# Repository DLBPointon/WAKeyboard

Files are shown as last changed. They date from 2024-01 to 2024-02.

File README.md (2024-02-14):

# WAK!

Whilst waiting for a replacement for a beautiful split keyboard, the Sofle v2, i jumped into the rabbit hole of Mechanical Keyboards. It didn't help that my daughter now wants her own, so here I am learning in public.

## Build Diary
[Find my build diary here](diary/diary.md)

# Summary
Clearly, there are some glaring faults here.
- The inch thick cavity is not good, if makes a bit of an echo chamber which makes quite the twang when a central button is pressed.
    - Next versions should seat the MCU on top ( like the lumberjack which I think is cool af )or have more fill inside the case. Maybe foam?

- Although the dedicated MCU socket is a good idea, to me anyway, it add ALOT of headroom. Perhaps, if the extra gpio pins pointed downwards so that the socket can pop out of the top and the pins point below... that would be a nice to have and potentially not hard to design...

- Better modelling of the case.

- MAGNETS! These would be much better to secure the top and bottom to the case.

- Wiring, cutting out segments didnt work... heat shrinking tiny bits of shrink. Next time, because there will be a next time. I'll be using magnetic wire.

## The Board
This will be a handwired, wired (for now) build using an RP2040 board (specifically this one [Waveshare RP2040 Plus](https://thepihut.com/products/rp2040-plus?variant=42405935612099), however if that doesn't work out then I have a Pi Pico WH in waiting--which I need to figure out how to hook up to a LiPo) programmed with KMK. For me this makes sense as i'm primarily a Python developer and KMK is built for the RP2040 ecosystem.

## Inspiration
### My Daughter (actual daughter, not a keyboard)
Wanted a "One piece" keyboard, apparently my split board was toooo space ship like... pfft.

### Lumberjack keyboard
I found this very early on in my search across the web, the one piece "split" with the controller in the middle looks pretty cool.

### Sofle v2
Of course, it's cool. I've tried to keep a similar-ish column stagger (more aggresive pinky, and no ring finger stagger). However, i've moved the clusters into the centre of the board ( something I may live to regret, but hey ho ).

## Design

I've designed this board using [Keyboard Layout Editor](http://www.keyboard-layout-editor.com/), writing it all in their raw data json field _before_ realising that there was GUI the whole time. This produces the contents of this file: [layout.json](data/layout.json).
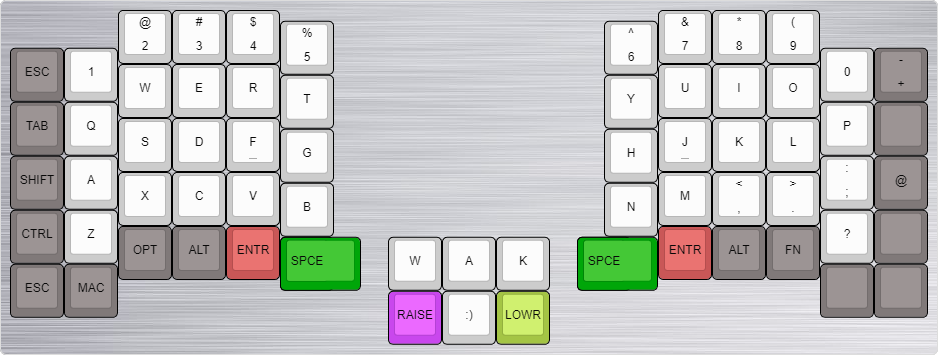
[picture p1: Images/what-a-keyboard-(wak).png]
WAK


Copy Pasting this into [KBFirmware](https://kbfirmware.com/), which I know is EOL but it's great for getting a quick and easy wiring diagram.
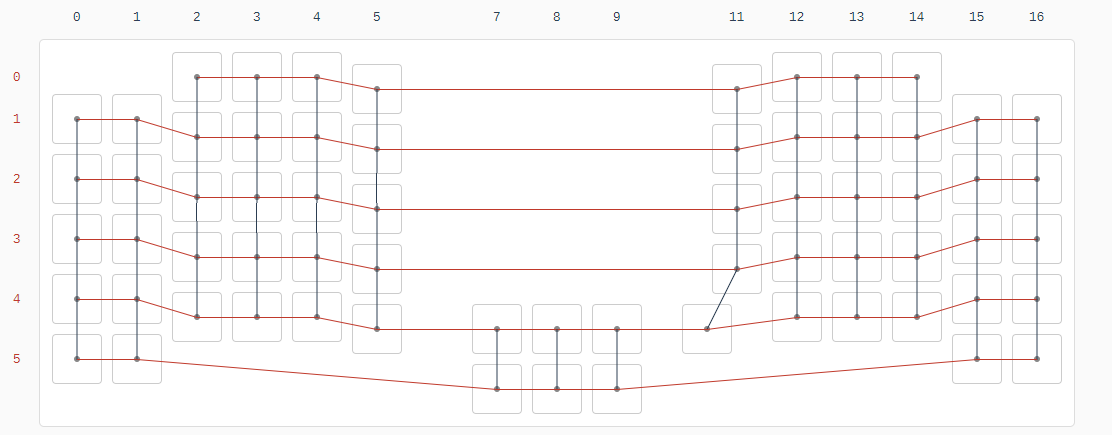
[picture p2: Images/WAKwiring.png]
Wiring


Pasting it into [swillkb's builder app](http://builder.swillkb.com/) will generate some CAD output too. Saved in the cad folder. This looks something like this:
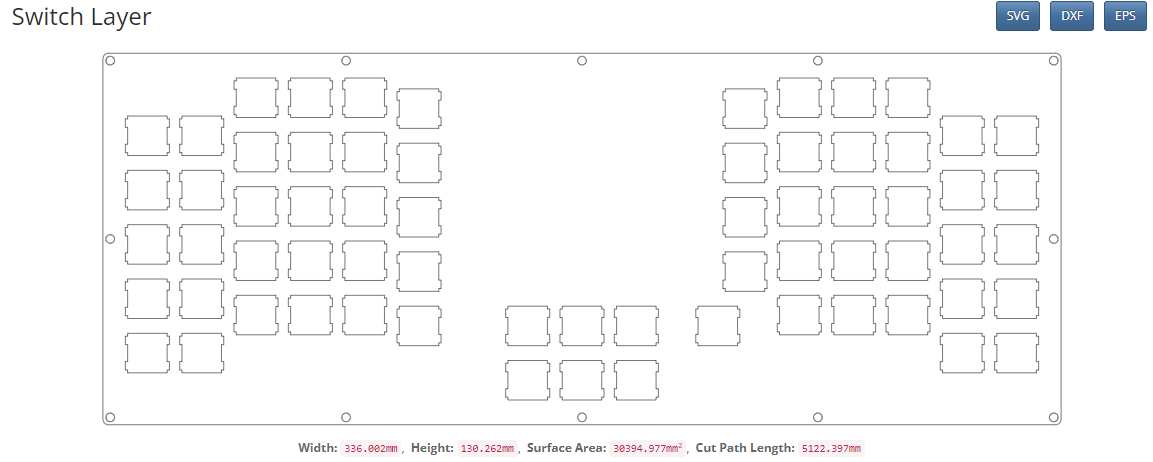
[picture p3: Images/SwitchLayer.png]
Switch Layer


I went to [laserboost](https://www.laserboost.com/en/create) to get the switch and bottom plate cut in Aluminium (This is only a prototype, and I feel like I should have found a 3d printer service too... lessons for the future)

I then thought, hmm... what would make this look very professional? People on the Reddit and the YouTube seem to like KiCad, so I gave it a go and came up with this:
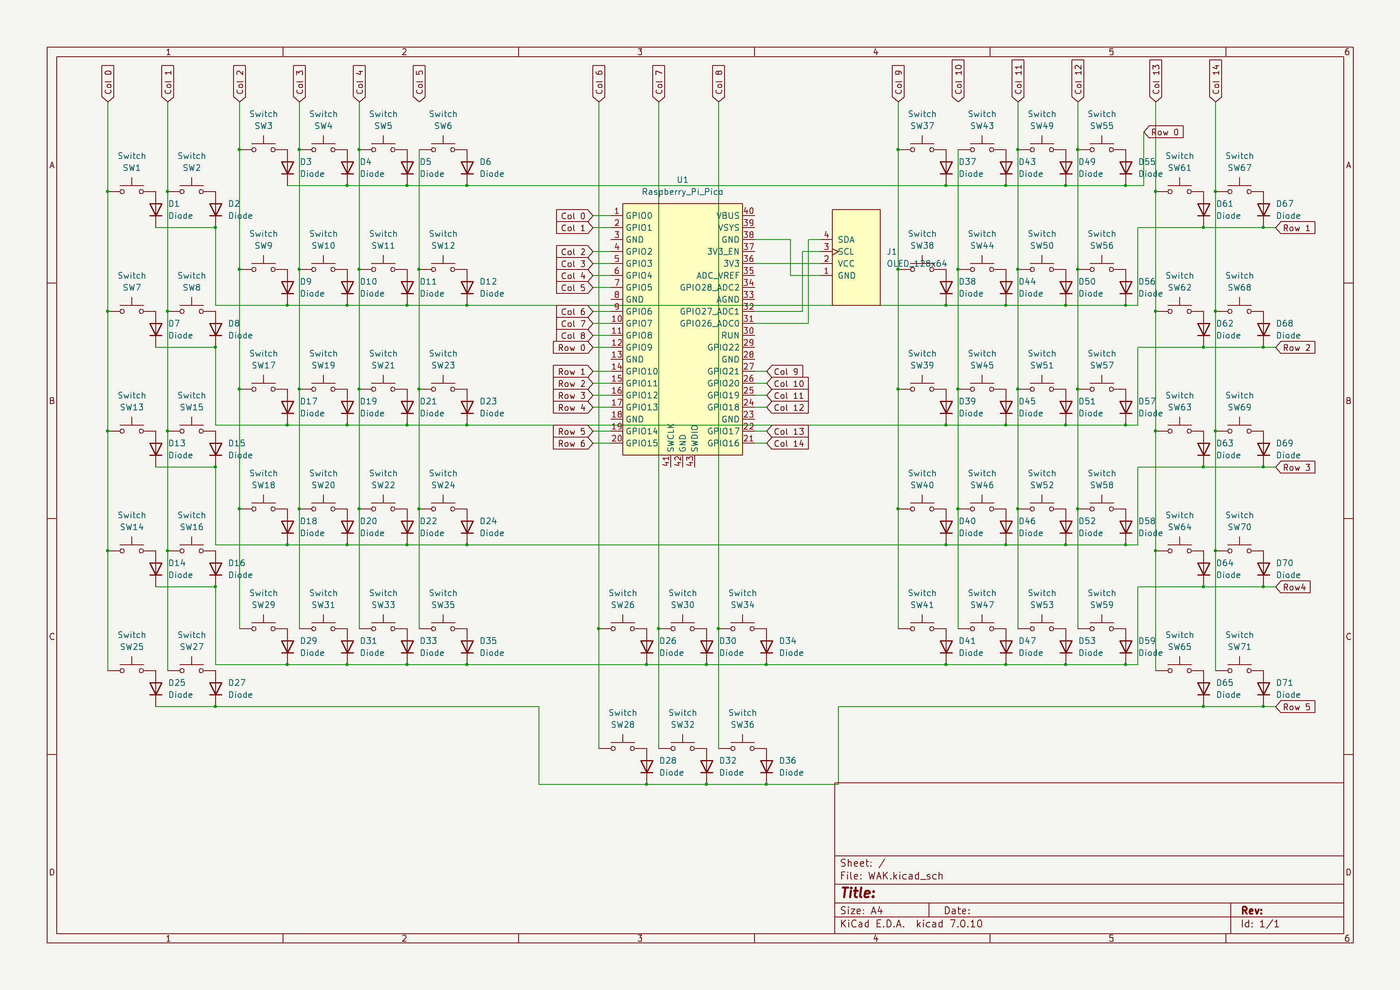
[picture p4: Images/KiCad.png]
KiCad Drawing


I also used this and the ScottoKeebs KiCad repo to generate a PCB, which I will not be getting printed as it is not completed (Some of the lines couldn't route to their pin so I temporarily gave up) and looks trash (from my currently uneducated gaze). It's more here to show it's easy to do after a 3rd viewing of Joe Scotto's tutorial. Look's cool though right?
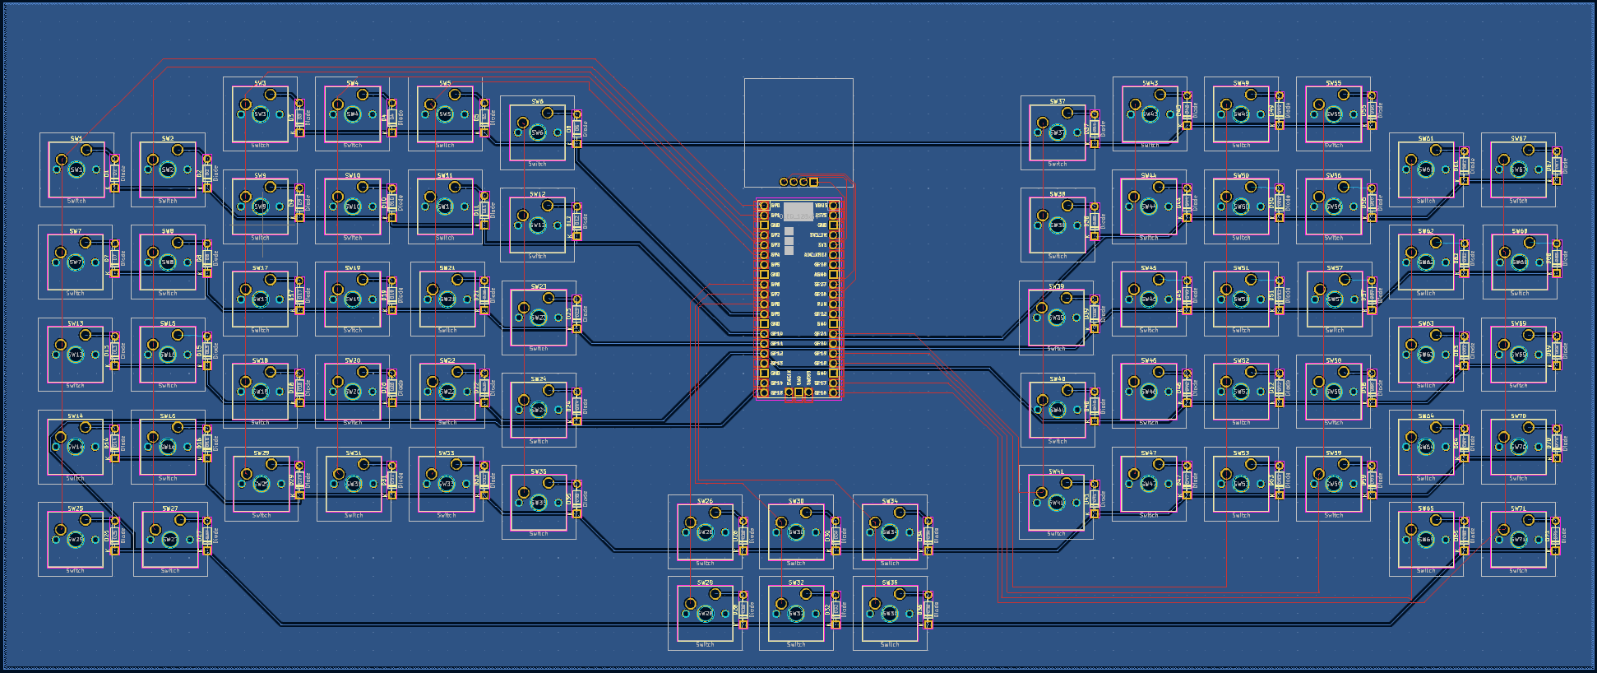
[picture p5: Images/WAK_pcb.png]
WAK_PCB


## Bill Of Materials

My new years resolution is no Amazon so my BoM so far is:

| Item | Cost | Use | Links | Notes |
|---|---|---|---|---|
| Diodes | £3.00 | For Dioding | [Mechboards.co.uk](https://mechboards.co.uk/collections/diodes/products/throughhole-diodes) | |
| MX Silent Reds | £36.00 | The switches | [Mechboards.co.uk](https://mechboards.co.uk/products/cherry-mx-silent-red?variant=41880305172685_) | Being swapped out for Gateron Oil Kings in my Sofle V2, they were on a 25% sale Bargin! |
| Main Header set for Pico * 2| £2.00 | for socketing | [PiHut](https://thepihut.com/products/male-headers-for-raspberry-pi-pico?variant=37979561001155) | *2 so i have a spare, fat fingers and tiny electronics don't go will together | 
| Pin breakout board | £4.20 | For use as my Socket | [PiHut](https://thepihut.com/products/pin-breakout-for-the-raspberry-pi-pico?variant=41952340508867) |Better than hotgluing header sets |
| Mounting Kit (screws and nut) | £11.50 | Screwing everything together | [PiHut](https://thepihut.com/products/mounting-kit-screws-and-nuts?variant=27740827601) ||
| Waveshare RP2040Plus 16MB | £11.80 | The microcontroller | [PiHut](https://thepihut.com/products/rp2040-plus?variant=42405935612099) | Only for a wired build |
| Solder Wire (lead free) | £8.00 | For soldering | [PiHut](https://thepihut.com/products/solder-wire-sac305-rohs-lead-free-0-5mm-02-diameter?variant=27739691025) ||
| USB-C to USB-C cable | £4.50 | To connect to the PC | [PiHut](https://thepihut.com/products/usb-c-to-usb-c-cable-1m?variant=42520365596867) ||
| Fermion Monochrome 128x32 I2C OLED | £9.80 | For visually checking you layer and adding images | [PiHut](https://thepihut.com/products/fermion-monochrome-0-91-128x32-i2c-oled-display-with-chip-pad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) | Dont hold the pins to the back of this for testing, you will slowly burn...|
| Metal plates | £70.00 | The case for the whole thing | [Lasterboost](https://www.laserboost.com/en/create) | I only got the switch and bottom plate, but really I should have just gone for a 3D printer service for this prototype |
| Wire | £8.00 | 60m of wire | [modellinglectronics](https://www.modellingelectronics.co.uk/products/solid-connecting-wire-1-0.6mm/) | 6 colours, 10m each not bad. Means I can have colour coded rows and columns for each area |
| Time spent researching | Priceless | So much stuff! | Reddit and Forums | Just so much... |
| 3D printed case | £22 | Safer than the sandwiched metal | [Surface Scan](https://www.surfacescan.co.uk/) | Pretty cool, find in the cad folder|

Adendum (Day 3)- I've replaced the wire with 1/0.8 bare copper wire (straightened like Joe Scotto's stuff) and heatshrink stuff. The insulated stuff was just too difficult to work with, however, i'll be able to use it bridge each side of the keyboard. So that everything can route around the controller.

So far that is around **£190.80**

Which I don't think is too bad, and could be brought under £100 by 3D printing the case or using smaller cheaper microcontroller.

I already have a soldering iron, but that was £20-ish and a Dremel for engraving and metal work, £100 but not needed at all.

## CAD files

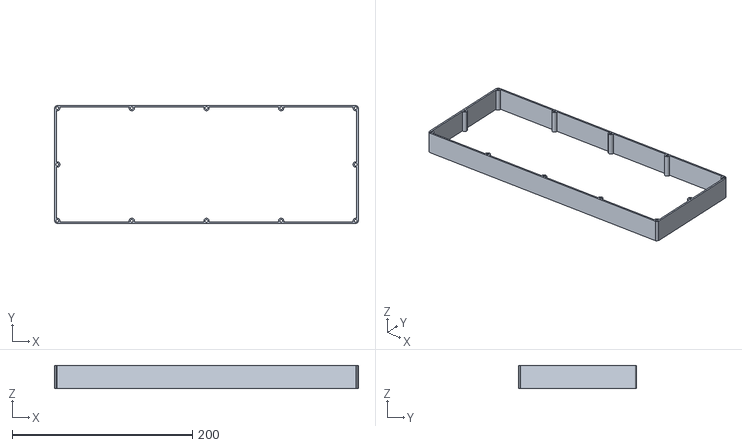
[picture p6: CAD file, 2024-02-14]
cad/WAKeyboard.stl
337.0 x 131.3 x 26.0

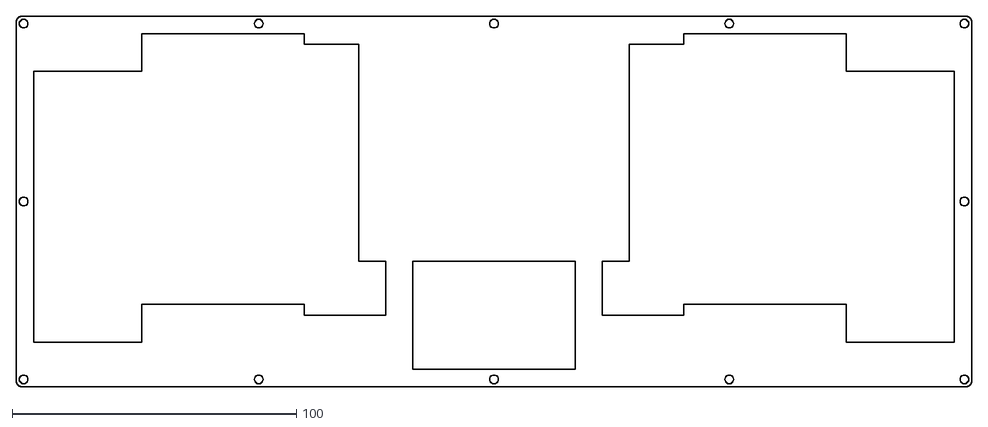
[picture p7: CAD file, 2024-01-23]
cad/top_plate.dxf
336.0 x 130.3

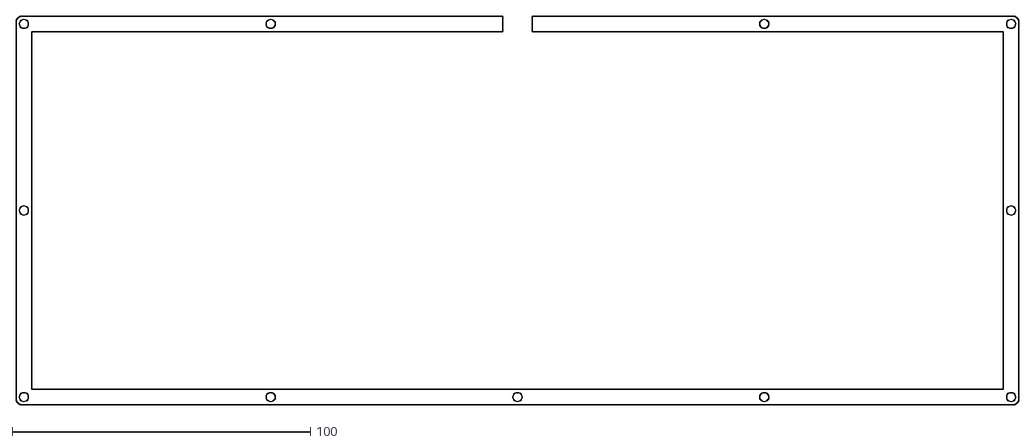
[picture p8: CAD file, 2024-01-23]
cad/open_midplate.dxf
336.0 x 130.3

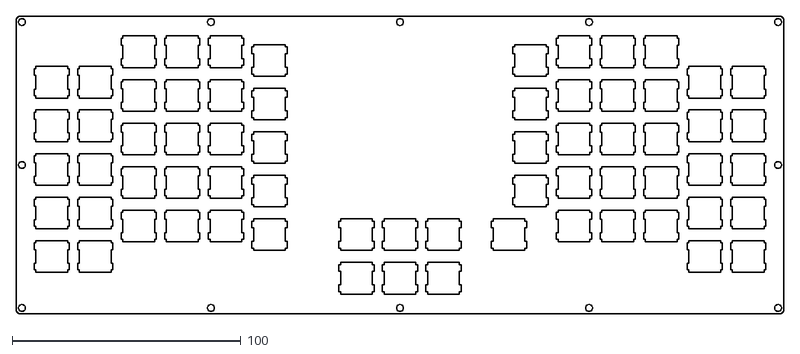
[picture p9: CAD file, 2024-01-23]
cad/switch_plate.dxf
336.0 x 130.3

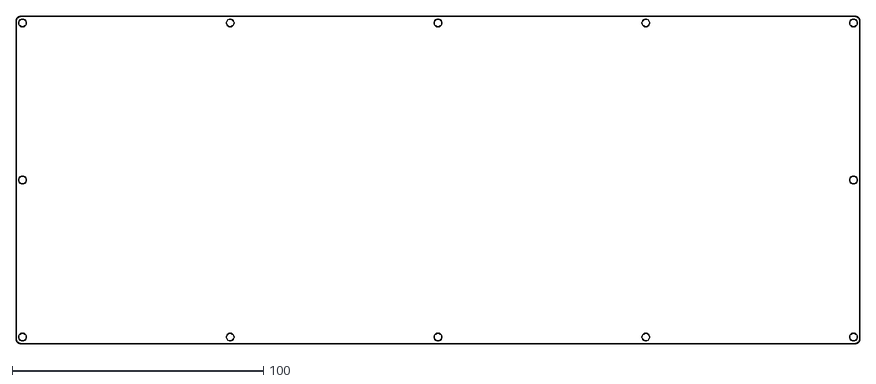
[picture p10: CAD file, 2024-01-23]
cad/bottom_plate.dxf
336.0 x 130.3

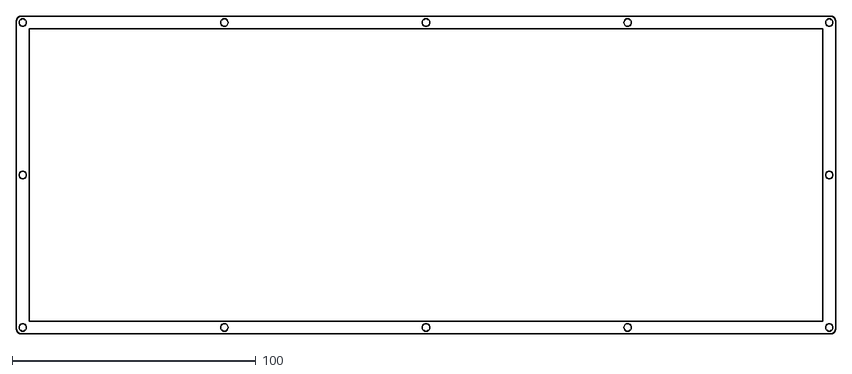
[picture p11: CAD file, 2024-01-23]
cad/closed_midplate.dxf
336.0 x 130.3

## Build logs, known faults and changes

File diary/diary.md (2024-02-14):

# 24th January 2024 (Day 1)
My PiHut order arrived!

I plugged my Waveshare RP2040 Plus and Raspberry Pi Pico into a mounting board and then into my computer, whilst pressing the bootslct button.

Now follow [this link](https://kmkfw.io/docs/Getting_Started/#tldr-quick-start-guide) on KMK to get started or if your too lazy...

- Downloaded the latest circuit python UF2 file and dropped it into the Pi's. Reboot by pressing the reset button or just re-plugging the device.

- Now download the kmk repo and drop the `kmk` folder and `boot.py` into the the Pi.

- Create a `code.py` or `main.py` in the top level directoy (where boot.py is) and add the following code:

```python
print("Starting")

import board

from kmk.kmk_keyboard import KMKKeyboard
from kmk.keys import KC
from kmk.scanners import DiodeOrientation

keyboard = KMKKeyboard()

keyboard.col_pins = (board.GP0,)
keyboard.row_pins = (board.GP1,)
keyboard.diode_orientation = DiodeOrientation.COL2ROW

keyboard.keymap = [
    [KC.A,]
]

if __name__ == '__main__':
    keyboard.go()
```

You may have to addapt the GP0 and GP1 to your board, these are the General Programmable pins, so don't assume they just mean pin and include ground pins.

_Viola_ 

Reset/boot your pi and use something to bridge GP0 and GP01, I had a jumper wire but you can use a paperclip too. Don't worry if the pi still comes up as an accessible drive, it will still work as a keyboard. Scratched my head for a while before just trying the pins and figuring I had done it right.

Once I got that work, I wrote the first version of my keymap ([found here](data/code_v1.py)) which only took some minor debugging before I found that KC.9 should have been KC.N9, any error will cause it to straight up not work.

And now I wait for everything else to turn up...

# 26th January 2024 (Day 2)

The switch and bottom plates, switches, diodes and wire have arrived!

The plates look great, and I have immediately populated it with _some_ help from my daughter (6 switches rushed into place) before realising I was 6 switches short, so off to mechboards again...

It's a good thing this is a handwired board because those switches wouldn't be coming out even if they wanted to.

Apologies for the shody photots.
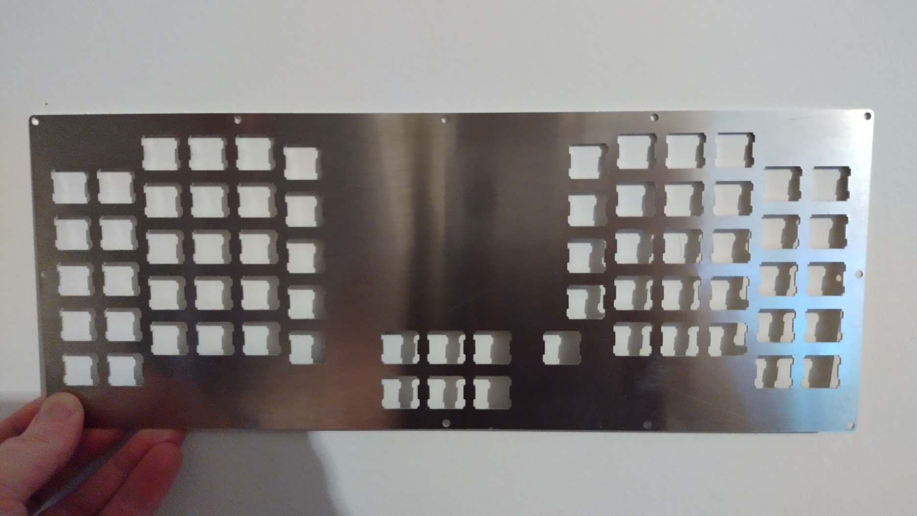
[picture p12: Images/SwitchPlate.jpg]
SwitchPlate


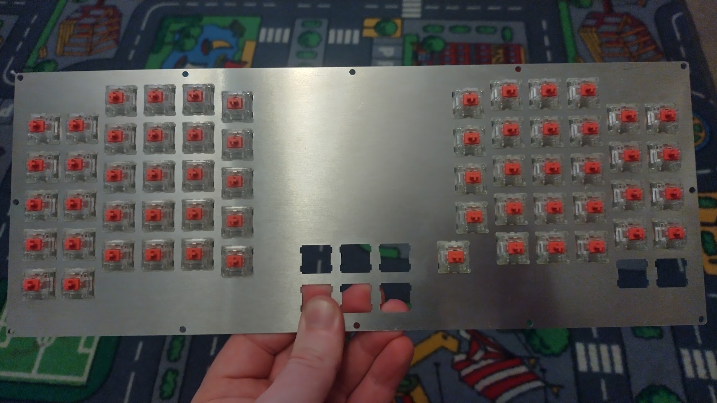
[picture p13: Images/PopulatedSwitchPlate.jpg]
PopSwitchPlate


6 switches off though...

I then spent the next half hour using these sausage finger to bend all my diodes in preparation for soldering day.

# 27th January 2024 (Day 3)
I tried prepping the wire, cutting the blue wire into strips suitable for the columns, however cutting out the sections for the soldering was pretty difficult. For that reason i'm going to follow Joe Scotto's lead and get my self some bare and larger wire with heat shrink. That will hopefully make life significantly easier.

# 28th January 2024 (Day 4)
New wire has arrived, the heat shrink just about holds onto it when shrunk. It is alot more flammable than i thought though, so when using a naked flame make sure to be significantly above the the flame.

Next time, get some significantly fatter wire, trying to solder lengths of wire which move just to inconvenience you is pretty annoying.

I now started wiring the matrix and damn does it take some time.

# 30th January 2024 (Day 5)
The final switches have arrived and I've now finished the rows and started on the columns with now look something like this (excuse the soldering, it's been 12 years since my last failed attempt).

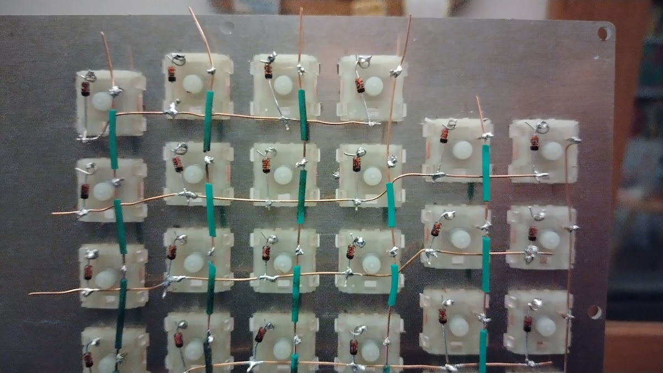
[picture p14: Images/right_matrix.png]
Right side matrix


And now it has suddenly dawned on me i've programmed the matrix backwards... I've done it as i look down on the back side of the board so left side QWERTY is actually right side YTREWQ. At least that is an east fix unlike the 8 backwards diodes I found!!!

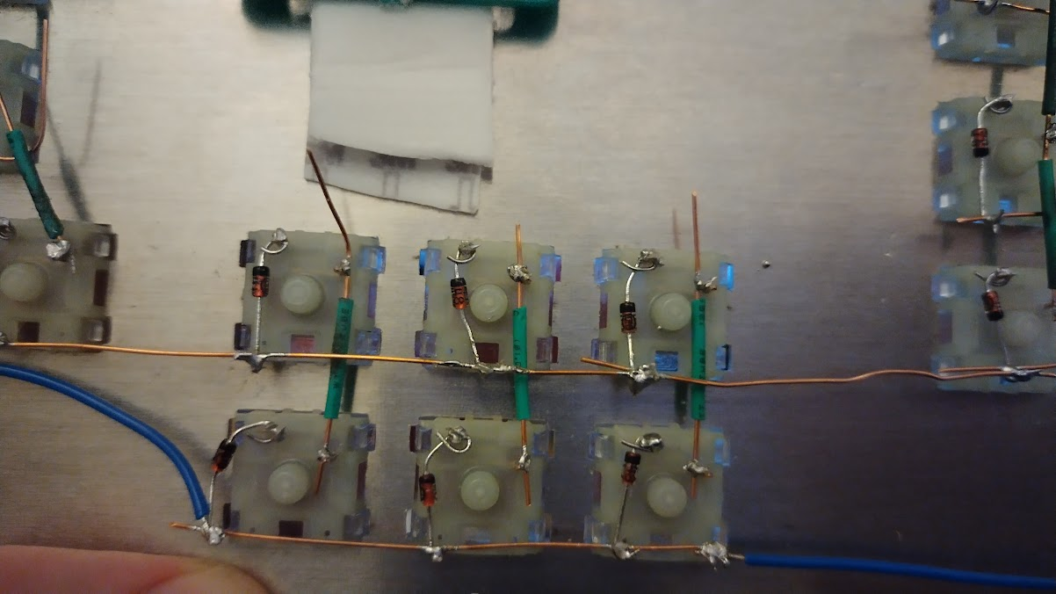
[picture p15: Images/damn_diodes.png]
Upside down diodes


Make this be a lesson, always double check the diode direction! I rushed it because the last of the switches finally arrived. But damn is this going to be a pain.

In good news, i have some jumper wire from older projects with raspberry pi's. I hooked up column 3,4,5,6 and row 3 and, after alot of head bashing with the waveshare (which suddenly doesn't work) and a quick replacement with a raspberry pi pico, it works! Never have I been so happy so see `sdfg` get printed out.

Next, it is finishing the columns, swapping out the diodes and then finally running the rowns and columns to some headers that can go into the pinout board.

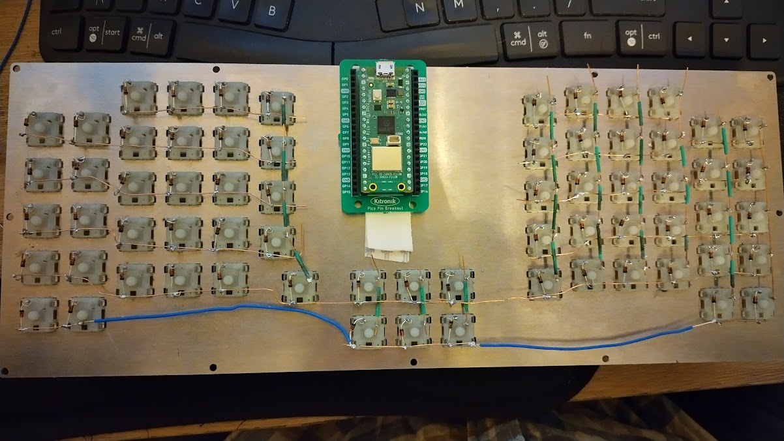
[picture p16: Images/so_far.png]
The keyboard so far


Yes that is 3M vecro hanging stuff, I had it laying around and for a prototype it ain't too bad. although, it and the Pi now ensures that at least the far end of the board will be about 0.8 inches thick and i've been told I'm not allowed to mount it on the top of the board as the black space **will** be engraved with a rainbow/heart or something equally cute. Orders are orders. So we are now looking at a sloped design.

My daughter has already designed v2 though. Using a rainbow GPIO extender and *shock* a split style board. So that will be pretty fun. I'm thinking of having it so that the gpio can be disconnected easily from the top to turn it into a game pad or be swapped out for other gpio cables (wouldn't it be cool if you could get custom ones... or at least a sleave).

# 1st February 2024 (Day 6)
It is done! 
I can't believe how long soldering can take.... but i'm going to end up doing more of this. Designing and making your own keyboard is quite a rush?!

I've soldered the diodes ( one i did twice as i resoldered the new one on upside down and didn't realise for 20 mins).

It took 2.5 hours soldering everything today (+ the 2 hours on previous days) and then another 1.5 hours of troubleshooting and re-soldering dodgey bit, which would immediately make the whole row work ( an absolute chef's kiss ).

So I started will connecting the two halfs together and then the columns:
Half Wired

Please don't judge the stripy nature of the pattern I went with. I thought it would be helpful and I ran out of colours to do what I wanted.

Next the rows, and the troubleshooting:
Final wiring

Troubleshooting, as said earlier, was fixed dodgey soldering and dodgey code. It turned out that one line had not enough keycodes, causing all the keys to get shifted 2 to the left which made it look as though the bottom row didn't work at all this was after re-soldering the whole row and then realising my mistake.

It may look horrific to a pro, but damn am I proud of it.

Now to pick my kid up from school, take her to the hadware shop and get some inch long m3's before convincing her to give me a final*5 design she wants etched onto the front. And then explain that her keycaps won't arrive for another 10 days :|

# 5th February 2024 (Day 5)
It turned out that the place i chose for 3d printing [Surface Scan](https://www.surfacescan.co.uk/) had to close due to everyone getting covid, which must have been a real pain for them, so we had to wait as few extra days. Which is fine, especially as the end product is great! My 3d modeling is quite literally non-existant, I managed to import the bottom plate into Autodesk Fusion and extrude the outline by about an inch ( because of the whole microcontroller _having_ to to internal ). I made sure that the walls were all obout 1.5mm thick for rigidity and presto. Find the stl in the cad folder.

Once it arrived, I had to do some artistic restructuring... e.g. i cut out a chunk which turned out be to be fair chunk. If I was just more patient then i could have actually measured the cut out and modelled it properly, however, i'm impatient and my boss (a 6yr old) is even less so.

It also turned out that the screw holes where perfect for the M3 screws to not need any nut. Bonus.

The final product, including the cut out:
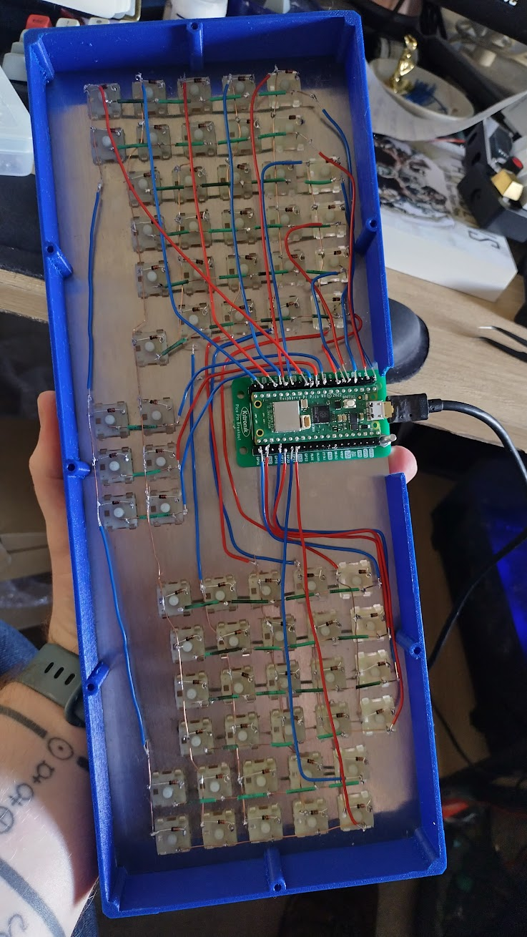
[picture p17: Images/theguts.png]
Guts of the keyboard


Also, say what you will about my wire pattern but it has actually helped me fund issues.... issues caused by myself but issues none the less. I dropped it and re-soldered a red wire to GND. It wasn't until testing I realised that the wires were red, red, blue instead of alternating. Fixed in a jiffy.

Ultimately we ended up with this:
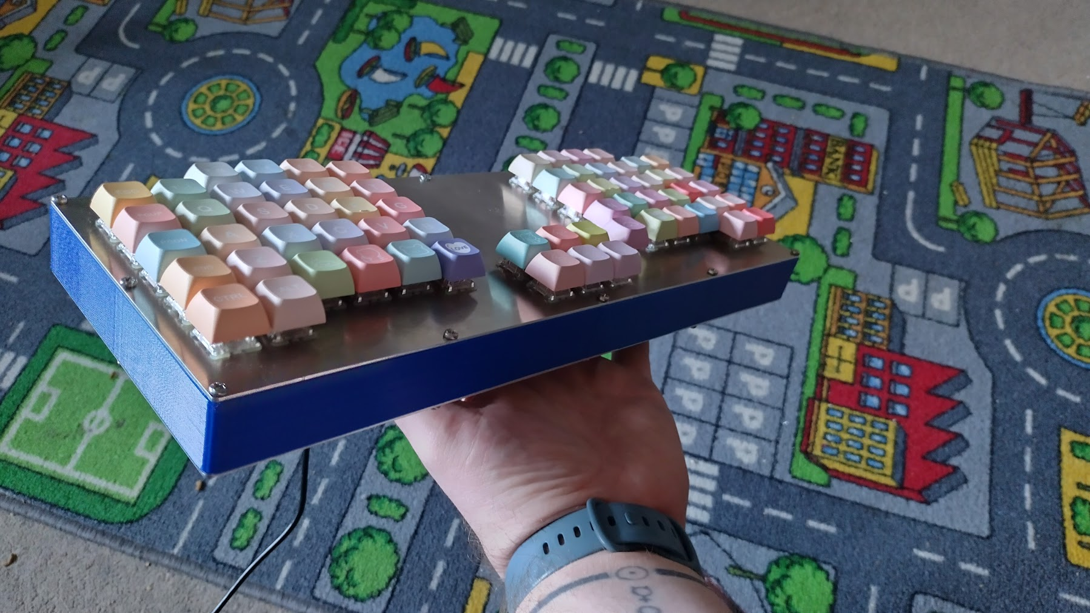
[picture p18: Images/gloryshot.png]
The whole thing


An inch thicc aluminium and 3d printed case, MX silent red switches with jelly baby keycaps from Etsy.
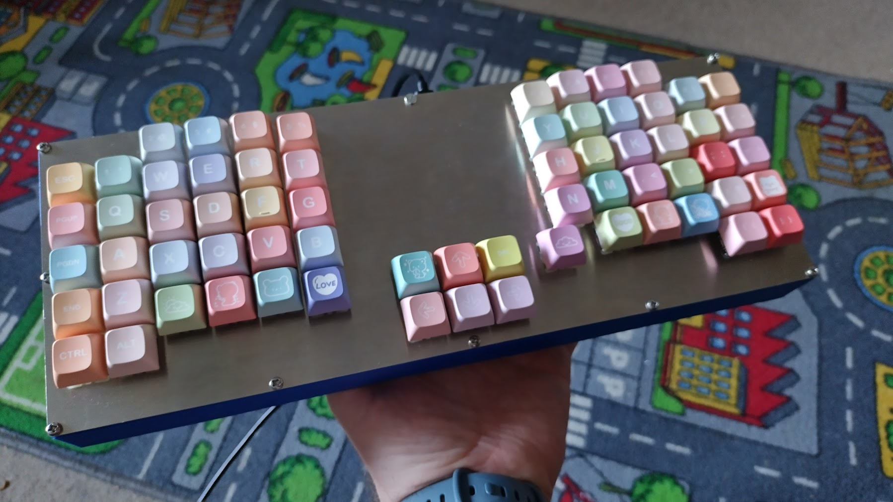
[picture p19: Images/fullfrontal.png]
Now from the front


# Next... Engraving

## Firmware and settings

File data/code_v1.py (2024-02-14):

print("Starting")

import board

from kmk.kmk_keyboard import KMKKeyboard
from kmk.keys import KC
from kmk.hid import HIDModes
from kmk.scanners import DiodeOrientation
from kmk.handlers.sequences import send_string
from kmk.extensions.media_keys import MediaKeys
from kmk.extensions.statusled import statusLED


keyboard = KMKKeyboard()
keyboard.extensions.append(MediaKeys())

statusLED = statusLED(led_pins=[board.GP26],brightness=30)
keyboard.extensions.append(statusLED)

WAK_W = send_string("What A Keyboard!!")
WAK_A = send_string("Amazing Keyboard!!")
WAK_K = send_string("Killer Keeb!!")
SMILE = send_string(":)")

keyboard.col_pins = (
    board.GP21, board.GP20, board.GP19, board.GP18, board.GP17, board.GP16,
    board.GP8, board.GP7, board.GP6,
    board.GP5, board.GP4, board.GP3, board.GP2, board.GP1, board.GP0
)
keyboard.row_pins = (
    board.GP10, board.GP11, board.GP12, board.GP13, board.GP14, board.GP9
)
keyboard.diode_orientation = DiodeOrientation.COL2ROW

keyboard.keymap = [
    [   KC.NO, KC.NO, KC.N2, KC.N3, KC.N4, KC.N5,           KC.NO, KC.NO, KC.NO,        KC.N6, KC.N7, KC.N8, KC.N9, KC.NO, KC.NO,
        KC.ESC, KC.N1, KC.W, KC.E, KC.R, KC.T,              KC.NO, KC.NO, KC.NO,        KC.Y, KC.U, KC.I, KC.O, KC.N0, KC.BSPC,
        KC.TAB, KC.Q, KC.S, KC.D, KC.F, KC.G,               KC.NO, KC.NO, KC.NO,        KC.H, KC.J, KC.K, KC.L, KC.P, KC.QUOT,
        KC.LSHIFT, KC.A, KC.X, KC.C, KC.V, KC.B,            KC.NO, KC.NO, KC.NO,        KC.N, KC.M, KC.COMM, KC.DOT, KC.SLSH, KC.GRV,
        KC.LCTRL, KC.Z, KC.LGUI, KC.LALT, KC.ENT, KC.SPACE, WAK_W, WAK_A, WAK_K,        KC.SPACE, KC.ENT, KC.RALT, KC.MUTE, KC.VOLU, KC.VOLD,
        KC.ESC, KC.RLD, KC.A, KC.A, KC.A, KC.A,         KC.MO(1), SMILE, KC.MO(2),  KC.A, KC.A, KC.A, KC.A, KC.VOLU, KC.VOLD,
    ],
]

if __name__ == '__main__':
    keyboard.go()

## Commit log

2024-01-23 Uploading work so far
    [WAK.kicad_sch, bottom_plate.dxf, closed_midplate.dxf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]
2024-01-25 Updating README with BoM
